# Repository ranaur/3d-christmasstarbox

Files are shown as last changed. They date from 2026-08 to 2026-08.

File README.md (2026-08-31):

# 3D Christmas Star Box

A 3D-printable Christmas star tree topper that doubles as a small box.
Designed in [OpenSCAD](https://openscad.org/) — fully parametric, all
dimensions can be tweaked at the top of each `star_box_*.scad` file.

There are 4 versions: Flat vs. Pyramid, and Default vs. Middle:

- **Flat** (`star_box_flat*.scad`) — the box has flat front and back
  faces.
- **Pyramid** (`star_box_pyramid*.scad`) — each half rises to a peak in
  the middle (classic 3D star look), sitting on a small straight rim
  (`rim_h`, default 5 mm) that carries the snap fit.
- **Default** (`star_box_flat.scad`, `star_box_pyramid.scad`) — the
  star's bottom point sinks into a star-shaped socket in the base.
- **Middle** (`star_box_flat_middle.scad`,
  `star_box_pyramid_middle.scad`) — a round mounting shaft between the
  two bottom star points inserts into a round socket in the base.

## How it works

- The **front** and **back** are star-shaped half-shells that snap
  together to close the box (snap ridge/tongue on the back clicks into a
  groove in the front, `clearance` = 0.25 mm).
- The **conic base** slides over the tip of the tree from below and
  locks the two halves together — via the bottom star point (default
  versions) or the mounting shaft (middle versions).
- In the middle versions each half carries a half-round shaft in the
  valley between the two bottom points; when the halves snap together
  they form a round shaft.

### Shaft parameters (middle versions)

| Parameter | Meaning | Default (flat / pyramid) |
|---|---|---|
| `shaft_r` | Shaft radius | 6 / 4.75 mm |
| `shaft_len` | Protrusion past the star valley | 25 mm |
| `shaft_embed` | Root depth into the star body | 6 mm |
| `socket_depth` | Socket depth in the cone | 20 / 15 mm |

Keep `shaft_r` below `thickness / 2` (flat) or `rim_h` (pyramid).

## Parts

Each version renders three parts:

| Part | Description | Print orientation |
|---|---|---|
| `front` | Front half-shell | Flat: face on the bed. Pyramid: rim on the bed, apex up |
| `back`  | Back half-shell with snap lip/tongue | Flat: face on the bed. Pyramid: tongue on the bed, apex up |
| `base`  | Conic base / tree-tip collar | Wide end on the bed |

Included STLs: `<variant>_<part>.stl` for every combination, e.g.
`flat_front.stl`, `pyramid_middle_base.stl`.

Print notes:

- Flat middle: the half-round shaft overhangs at the mating plane when
  the face is on the bed — enable supports under the shaft.
- Pyramid: the hollow interior of the pyramid faces are shallow
  overhangs — print with supports, solid infill, or increase `peak` for
  steeper facets.

## Default dimensions

- Star: 150 mm tip-to-tip; flat: 40 mm deep, 2 mm walls; pyramid:
  28 mm peak per half on a 5 mm rim, 2.4 mm walls
- Cone: 50–60 mm tall depending on version, fits a tree tip up to
  ~22–26 mm diameter
- Fit clearance: 0.25 mm (adjust `clearance` for your printer)

## Regenerating the STLs

With GNU make and OpenSCAD on the PATH:

```sh
make                # all 12 STLs (3 parts x 4 variants)
make pyramid_middle # one variant
make OPENSCAD="C:/Program Files/OpenSCAD/openscad.com"  # custom binary
```

Or render a single part directly:

```sh
openscad -o flat_front.stl -D part=\"front\" star_box_flat.scad
```

Set `part = "assembly"` in the file (or via `-D`) to preview the whole
assembly in the OpenSCAD GUI.

## Print settings (suggested)

- Material: PETG or PLA
- Layer height: 0.2 mm, 2–3 perimeters
- If the snap fit is too tight/loose, tune `clearance` and `bump`

## Credits & license

This project was heavily made by AI ([Devin](https://devin.ai) — design,
OpenSCAD code, STLs and docs), directed by a human.

Released under [CC0 1.0](LICENSE) — public domain dedication. Use it,
remix it, print it, sell it; no attribution required.

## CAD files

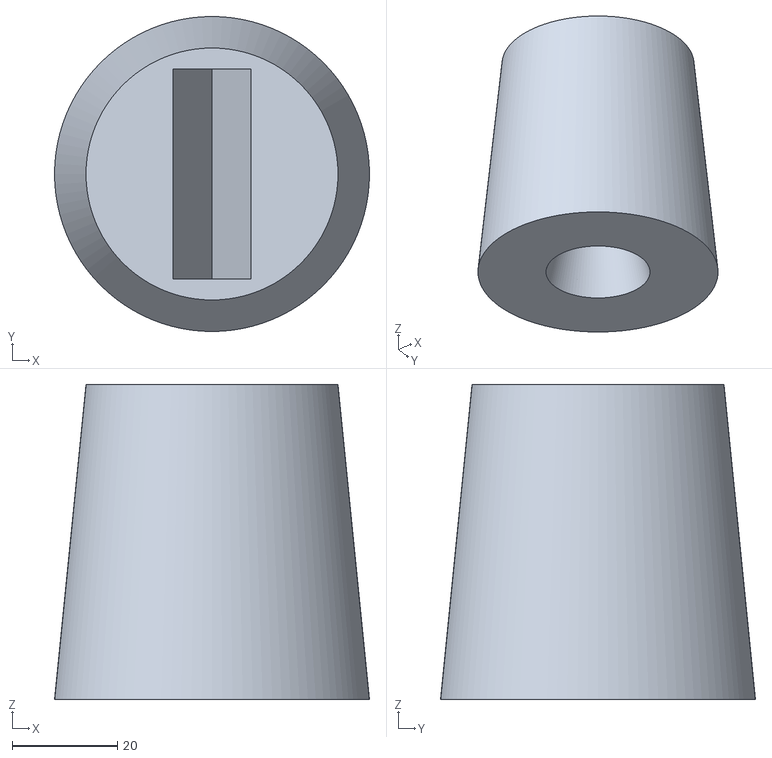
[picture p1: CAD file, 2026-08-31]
flat_base.stl
60.0 x 60.0 x 60.0

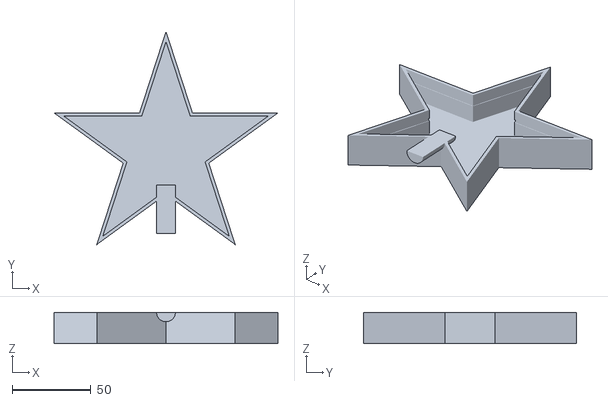
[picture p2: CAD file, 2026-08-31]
flat_middle_front.stl
142.7 x 135.7 x 20.0

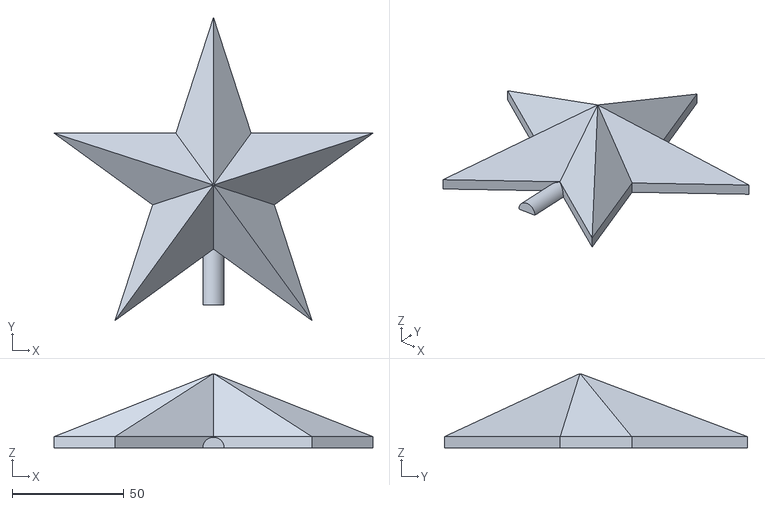
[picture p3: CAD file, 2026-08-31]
pyramid_middle_front.stl
142.7 x 135.7 x 33.0

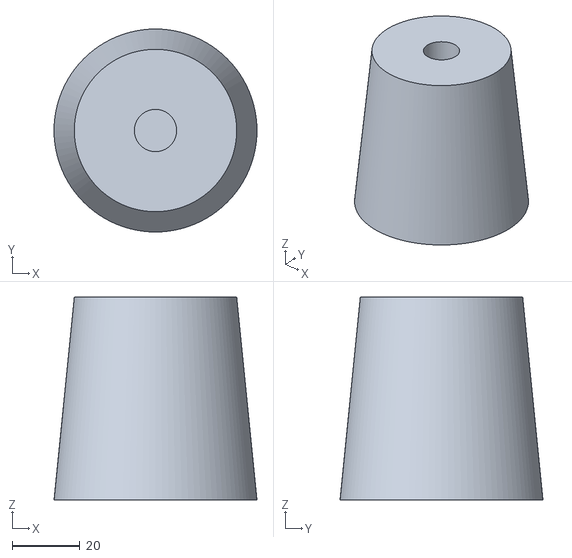
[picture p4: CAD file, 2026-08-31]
flat_middle_base.stl
60.0 x 60.0 x 60.0

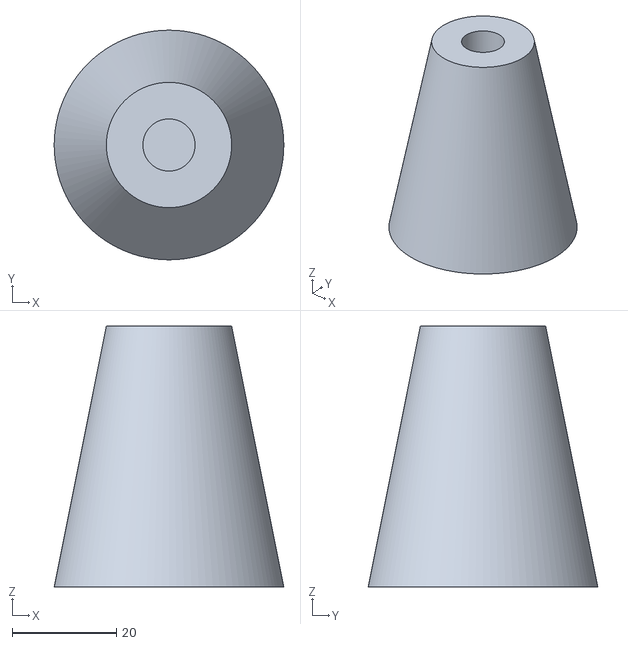
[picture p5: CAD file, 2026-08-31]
pyramid_middle_base.stl
44.0 x 44.0 x 50.0

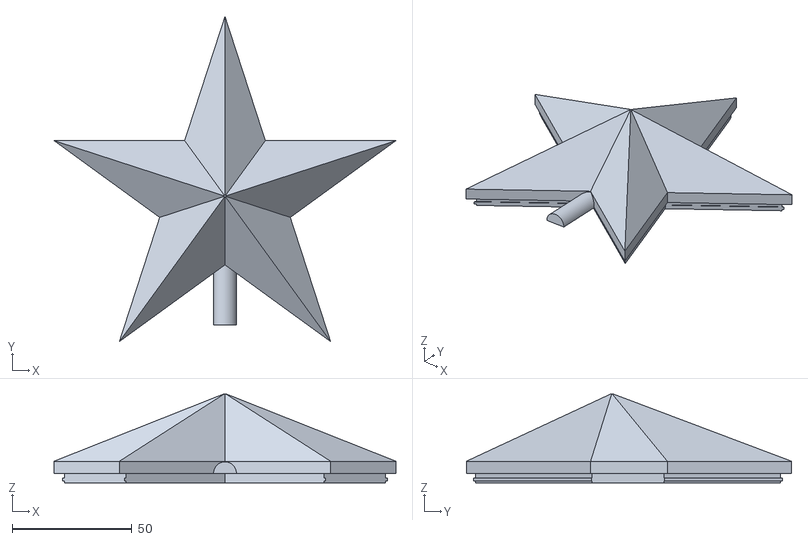
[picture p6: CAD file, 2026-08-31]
pyramid_middle_back.stl
142.7 x 135.7 x 37.0

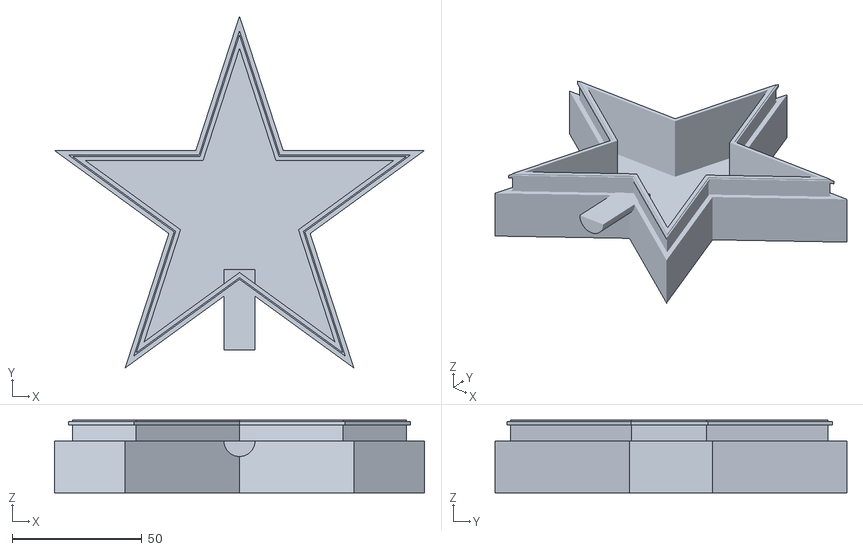
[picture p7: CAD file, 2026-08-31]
flat_middle_back.stl
142.7 x 135.7 x 28.0

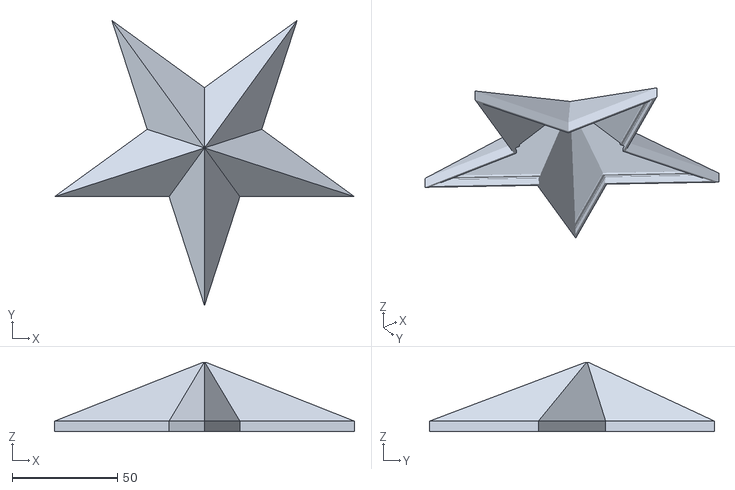
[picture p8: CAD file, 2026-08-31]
pyramid_front.stl
142.7 x 135.7 x 33.0

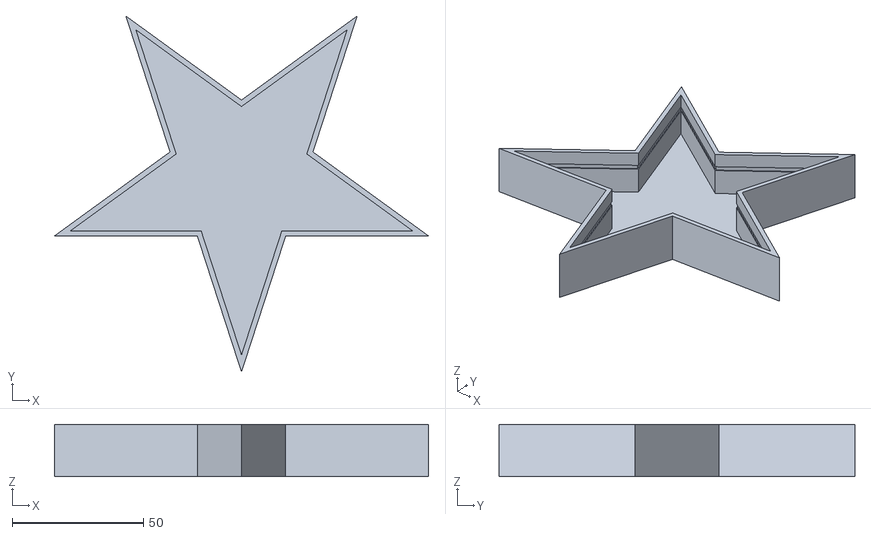
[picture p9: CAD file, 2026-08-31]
flat_front.stl
142.7 x 135.7 x 20.0

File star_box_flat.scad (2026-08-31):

// Christmas Star Tree-Topper Box
// Three printable parts:
//   part = "front"    -> front half-shell (star shaped, prints face down)
//   part = "back"     -> back half-shell with snap lip (prints face down)
//   part = "base"     -> conic base that slides over the tree tip and
//                        locks the two halves at the bottom star point
//   part = "assembly" -> preview of all parts assembled
//
// Render STLs with:
//   openscad -o front.stl -D part=\"front\" star_box.scad
//
// All dimensions in millimeters.

part = "assembly";
//part = "front";
//part = "back";
//part = "base";

/* ---------- Star parameters ---------- */
star_points   = 5;
R             = 75;            // outer radius (tip to center) -> 150 mm tip-to-tip
r             = R * 0.382;     // inner radius of the pentagram
thickness     = 40;            // total box depth (front + back)
wall          = 2;             // wall / face thickness
clearance     = 0.25;          // printing clearance for fits

/* ---------- Snap-fit parameters ---------- */
lip_h         = 8;             // how far the back lip slides into the front
lip_w         = 1.6;           // lip wall width
bump          = 0.5;           // snap ridge interference
ridge_h       = 1.2;           // snap ridge band height
groove_h      = 1.8;           // groove band height (slightly taller)

/* ---------- Conic base parameters ---------- */
cone_h        = 60;            // cone height
cone_r_bottom = 30;            // outer radius at the wide (bottom) end
cone_r_top    = 24;            // outer radius at the top end
cone_wall     = 3;             // minimum cone wall
socket_depth  = 22;            // how deep the star bottom tip sinks into the cone
tree_hole_r   = 13;            // tree tip hole radius at the bottom
tree_hole_top = 5;             // tree tip hole radius at the top of the hole
tree_hole_h   = 34;            // tree tip hole depth (from the bottom)

$fn = 96;
half = thickness / 2;

/* ---------- 2D star ---------- */
module star2d() {
    // one point straight down (-Y), so the bottom tip meets the cone
    polygon([for (i = [0 : 2 * star_points - 1])
        let (a = -90 + i * 180 / star_points,
             rad = (i % 2 == 0) ? R : r)
        [rad * cos(a), rad * sin(a)]]);
}

module star_offset(d) { offset(delta = d) star2d(); }

/* ---------- Front half-shell ----------
   Prints as modeled: outer face on the bed (z = 0), cavity opening up. */
module front() {
    difference() {
        linear_extrude(half) star2d();
        // cavity
        translate([0, 0, wall])
            linear_extrude(half) star_offset(-wall);
        // snap groove in the inner wall, where the back lip's ridge lands
        translate([0, 0, half - lip_h + 0.6])
            linear_extrude(groove_h) difference() {
                star_offset(-wall + bump - 0.1);
                star_offset(-wall - clearance);
            }
    }
}

/* ---------- Back half-shell ----------
   Same shell as the front plus an inner lip with a snap ridge. */
module back() {
    // shell
    difference() {
        linear_extrude(half) star2d();
        translate([0, 0, wall])
            linear_extrude(half) star_offset(-wall);
    }
    // lip that slides inside the front cavity, rising from the floor
    translate([0, 0, wall])
        linear_extrude(half - wall + lip_h) difference() {
            star_offset(-wall - clearance);
            star_offset(-wall - clearance - lip_w);
        }
    // snap ridge near the lip tip
    translate([0, 0, half + lip_h - 0.6 - ridge_h])
        linear_extrude(ridge_h) difference() {
            star_offset(-wall - clearance + bump);
            star_offset(-wall - clearance - lip_w);
        }
}

/* ---------- Assembled star box (for the cone socket) ---------- */
module star_solid(extra = 0) {
    // full closed box outline, slightly enlarged by `extra` for clearance
    linear_extrude(thickness) star_offset(extra);
}

/* ---------- Conic base ----------
   Modeled in its printing orientation: wide end on the bed, axis = Z.
   In use it is flipped is not needed: tree tip enters from the bottom,
   the star's bottom point snaps into the socket cut in the top. */
module base() {
    difference() {
        cylinder(h = cone_h, r1 = cone_r_bottom, r2 = cone_r_top);
        // tree tip hole from the bottom
        translate([0, 0, -0.01])
            cylinder(h = tree_hole_h, r1 = tree_hole_r, r2 = tree_hole_top);
        // star-tip socket cut into the top: the star (with clearance)
        // positioned tip-down, sunk socket_depth into the cone
        translate([0, 0, cone_h - socket_depth + R])
            rotate([90, 0, 0])
                translate([0, 0, -thickness / 2])
                    star_solid(clearance);
    }
}

/* ---------- Assembly preview ---------- */
module assembly() {
    color("firebrick") front();
    color("darkred") translate([0, 0, thickness]) mirror([0, 0, 1]) back();
    color("goldenrod")
        translate([0, -R + socket_depth - cone_h, thickness / 2])
            rotate([-90, 0, 0]) base();
}

if (part == "front")    front();
if (part == "back")     back();
if (part == "base")     base();
if (part == "assembly") assembly();

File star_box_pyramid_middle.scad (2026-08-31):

// Christmas Star Tree-Topper Box — pyramidal version
// Like star_box.scad, but the front and back are faceted star pyramids
// (higher in the middle) sitting on a small straight rim that carries
// the snap fit.
//
// Parts:
//   part = "front"    -> front pyramidal half-shell (prints rim down)
//   part = "back"     -> back pyramidal half-shell with snap tongue
//   part = "base"     -> conic base that slides onto the mounting shaft
//                        between the two bottom points
//   part = "assembly" -> preview of all parts assembled
//
// Render STLs with:
//   openscad -o front.stl -D part=\"front\" star_box_pyramid.scad
//
// All dimensions in millimeters.

part = "assembly";

/* ---------- Star parameters ---------- */
star_points   = 5;
R             = 75;            // outer radius -> 150 mm tip-to-tip
r             = R * 0.382;     // inner radius of the pentagram
peak          = 28;            // pyramid height (apex above the rim)
rim_h         = 5;             // straight rim height per half (the "base")
wall          = 2.4;           // wall thickness
clearance     = 0.25;          // printing clearance for fits
star_rot      = 36;            // one point straight up, valley straight down

/* ---------- Mounting shaft (between the two bottom points) ---------- */
shaft_r       = 4.75;          // shaft radius (keep below rim_h)
shaft_len     = 25;            // how far the shaft protrudes past the valley
shaft_embed   = 6;             // how far the shaft roots into the star body

/* ---------- Snap-fit parameters ---------- */
lip_p         = 4;             // how far the back tongue protrudes past its rim
bump          = 0.3;           // snap ridge interference
ridge_h       = 1.2;           // snap ridge band height
groove_h      = 1.8;           // groove band height (slightly taller)
ridge_z0      = 0.8;           // ridge start, measured from the tongue tip

/* ---------- Conic base parameters ---------- */
cone_h        = 50;
cone_r_bottom = 22;
cone_r_top    = 12;
socket_depth  = 15;            // how deep the shaft sinks into the cone
tree_hole_r   = 11;
tree_hole_top = 4;
tree_hole_h   = 30;

$fn = 96;

/* ---------- 2D star ---------- */
module star2d() {
    polygon([for (i = [0 : 2 * star_points - 1])
        let (a = -90 + star_rot + i * 180 / star_points,
             rad = (i % 2 == 0) ? R : r)
        [rad * cos(a), rad * sin(a)]]);
}

module star_offset(d) { offset(delta = d) star2d(); }

// ring between two offsets of the star outline, extruded h at z0
module ring(o_out, o_in, z0, h) {
    translate([0, 0, z0])
        linear_extrude(h) difference() {
            star_offset(o_out);
            star_offset(o_in);
        }
}

/* ---------- Pyramidal half-shell (rim + faceted star pyramid) ----------
   Modeled in print orientation: open face / rim at z = 0, apex up.
   Inner pyramid faces are shallow overhangs — print with supports or
   solid infill, or increase `peak` for steeper facets. */
module half_shell(rim = rim_h) {
    // rim ring
    ring(0, -wall, 0, rim);
    // pyramid shell: outer faceted pyramid minus inner cavity pyramid
    translate([0, 0, rim]) difference() {
        linear_extrude(peak, scale = 0.01) star_offset(0);
        translate([0, 0, -0.01])
            linear_extrude(peak - wall, scale = 0.01) star_offset(-wall);
    }
}

/* ---------- Half of the mounting shaft ----------
   Full cylinder along -Y from the bottom valley, cut at the mating
   plane (z = 0), keeping the z >= 0 half. Each half-shell carries one
   half; together they form a round shaft the base slides onto. */
module half_shaft() {
    intersection() {
        translate([0, -(r - shaft_embed), 0])
            rotate([90, 0, 0])
                cylinder(h = shaft_len + shaft_embed, r = shaft_r);
        translate([-2 * R, -2 * R, 0]) cube([4 * R, 4 * R, 2 * shaft_r]);
    }
}

/* ---------- Front: recess + snap groove in the rim ---------- */
module front() {
    difference() {
        union() {
            half_shell();
            half_shaft();
        }
        // recess for the back tongue: inner half of the rim wall removed
        ring(-wall / 2, -wall - 0.1, -0.01, lip_p + 0.06);
        // snap groove in the recess wall
        ring(-wall / 2 + bump + 0.05, -wall - 0.1,
             lip_p - ridge_z0 - ridge_h - (groove_h - ridge_h) / 2, groove_h);
    }
}

/* ---------- Back: protruding tongue with snap ridge ---------- */
module back() {
    // tongue (tip on the bed at z = 0), mating plane at z = lip_p
    ring(-wall / 2 - clearance, -wall, 0, lip_p + 0.01);
    // snap ridge near the tongue tip
    ring(-wall / 2 - clearance + bump, -wall, ridge_z0, ridge_h);
    // rim, pyramid and shaft half above the mating plane
    translate([0, 0, lip_p]) {
        half_shell();
        half_shaft();
    }
}

/* ---------- Conic base ----------
   Modeled in print orientation: wide end on the bed, axis = Z.
   A round socket in the top receives the mounting shaft. */
module base() {
    difference() {
        cylinder(h = cone_h, r1 = cone_r_bottom, r2 = cone_r_top);
        translate([0, 0, -0.01])
            cylinder(h = tree_hole_h, r1 = tree_hole_r, r2 = tree_hole_top);
        // shaft socket
        translate([0, 0, cone_h - socket_depth])
            cylinder(h = socket_depth + 0.01, r = shaft_r + clearance);
    }
}

/* ---------- Assembly preview ---------- */
module assembly() {
    color("firebrick") mirror([0, 0, 1]) front();
    color("darkred") translate([0, 0, -lip_p]) back();
    color("goldenrod")
        translate([0, -(r + shaft_len) + socket_depth - cone_h, 0])
            rotate([-90, 0, 0]) base();
}

if (part == "front")    front();
if (part == "back")     back();
if (part == "base")     base();
if (part == "assembly") assembly();

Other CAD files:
back.stl
base.stl
front.stl
pyramid_base.stl
pyramid_back.stl
flat_back.stl
star_box_flat_middle.scad

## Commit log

2026-08-31 Add parametric Christmas star box (OpenSCAD + STLs)
    [back.stl, base.stl, front.stl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]
2026-08-31 Add pyramidal star variant with rim snap fit
    [pyramid_back.stl, pyramid_base.stl, pyramid_front.stl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]
2026-08-31 Mount pyramidal star via round shaft between bottom points
    [pyramid_back.stl, pyramid_base.stl, pyramid_front.stl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]
2026-08-31 Mount flat star via round shaft between bottom points
    [back.stl, base.stl, front.stl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]
2026-08-31 organizing middle and non-middle versions of files
    [star_box_pyramid_middle.scad, star_box_vflat.scad]
2026-08-31 Rewrite README for both variants and shaft mount
2026-08-31 Add Makefile rendering all 12 STLs; rename STLs per variant
    [flat_back.stl, flat_base.stl, flat_front.stl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]
2026-08-31 Remove old STL names
    [back.stl, base.stl, front.stl]
